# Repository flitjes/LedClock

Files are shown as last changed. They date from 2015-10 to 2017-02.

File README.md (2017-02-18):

A project for creating ledclock. 
The project contains the source for the actual clock and is depended
on a couple of breakouts, RTC, LDR and PIR.

This is tied together with an msp430g2553 to display the time on a ledclock
and be energy sufficient.

Besides the software I've made a 3D drawing which will be milled out of a mix
of materials, plexiglas, carbonfiber and MDF.

Protocol:
Set the time
time=12:10:04
start

setcolor=[id][rgb code]
id 0 = HOUR
id 1 = MINUTE
id 2 = SECOND (not implemented)
id 3 = BACKGROUND (not implemented)

Set the color
setcolor=0ffddff
start

Example with netcat
nc -u 192.168.4.1 12345
setcolor=0ff00ff

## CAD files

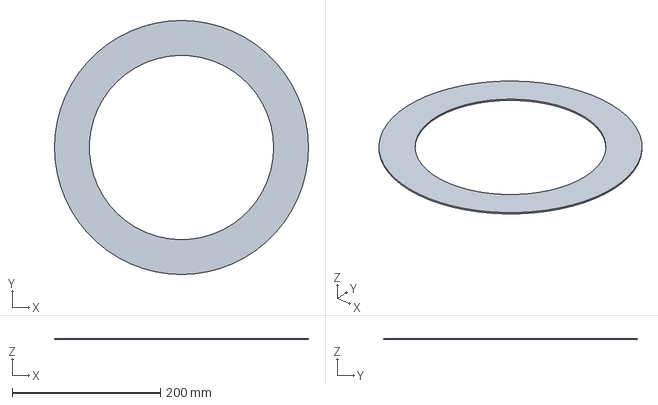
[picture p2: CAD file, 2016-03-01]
FreeCAD/topplate.stp
342.3 x 342.3 x 2.00 mm

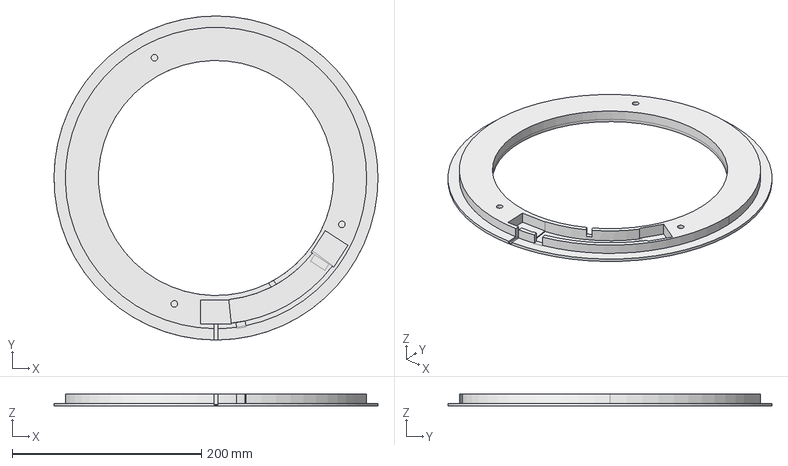
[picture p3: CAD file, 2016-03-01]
FreeCAD/ledclock_base_cutout.fcstd
342.3 x 342.3 x 13.0 mm

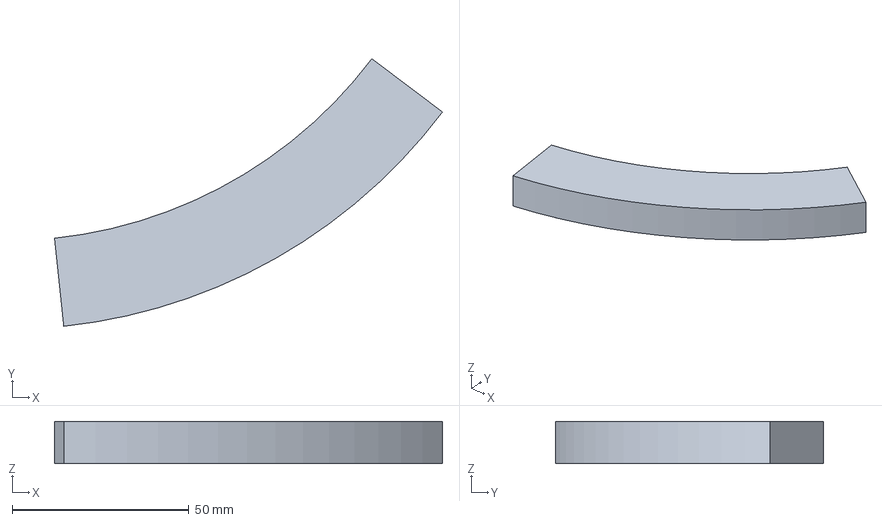
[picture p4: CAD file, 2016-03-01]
FreeCAD/pcb.stp
109.6 x 75.6 x 12.0 mm

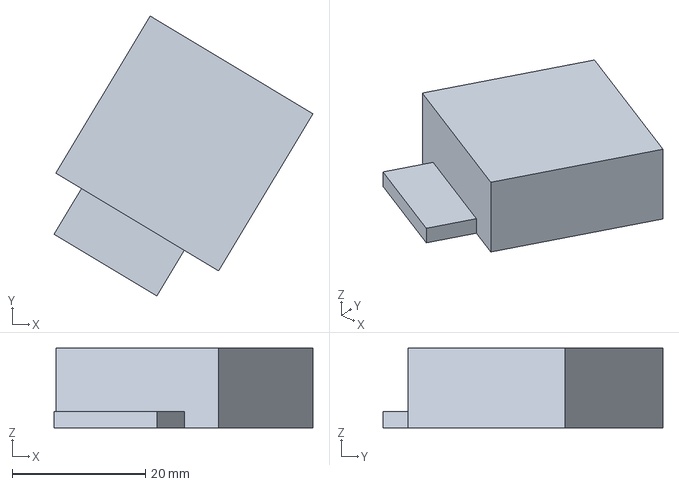
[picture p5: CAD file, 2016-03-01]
FreeCAD/RTC.stp
38.9 x 42.0 x 12.0 mm

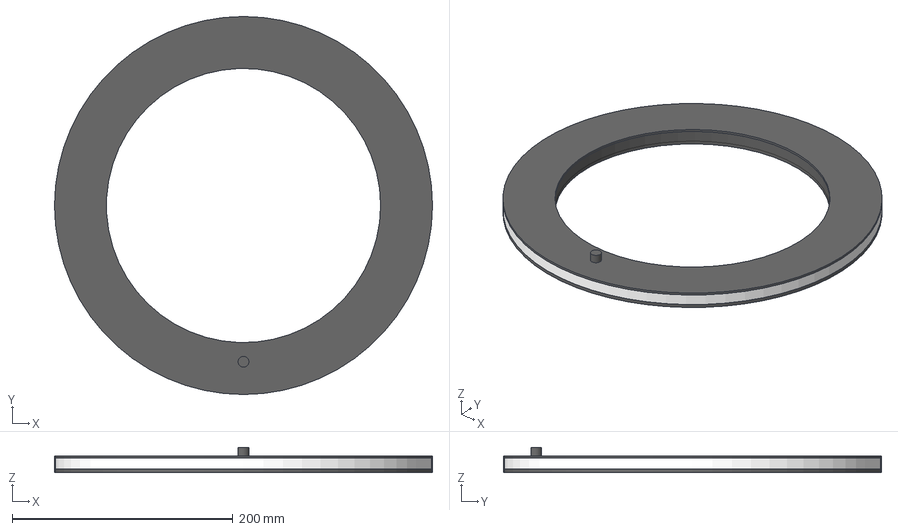
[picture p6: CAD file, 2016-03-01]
FreeCAD/ledclock.fcstd
342.3 x 342.3 x 22.7 mm
topplate_ring
RTC breakout
PIR breakout
Bottom part
PCB
difuser_ring

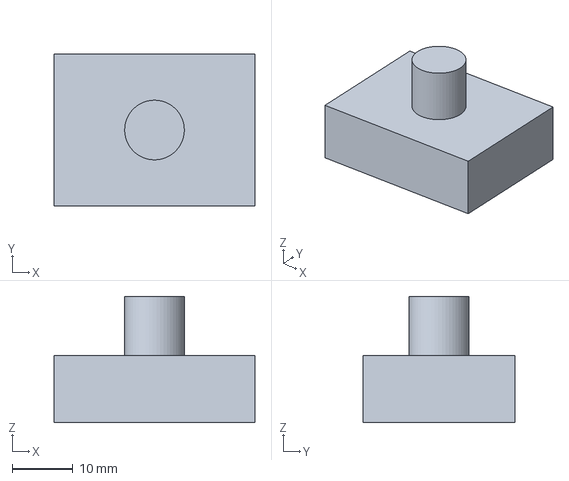
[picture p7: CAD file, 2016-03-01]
FreeCAD/pir_sensor.stp
33.0 x 25.0 x 20.7 mm

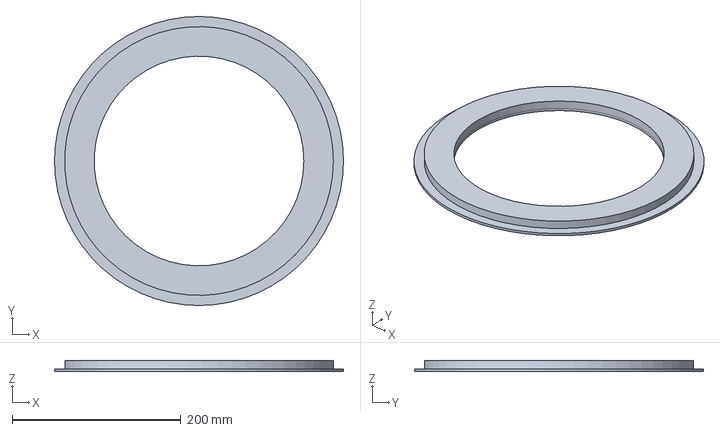
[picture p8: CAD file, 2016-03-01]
FreeCAD/bottom.stp
342.3 x 342.3 x 13.0 mm

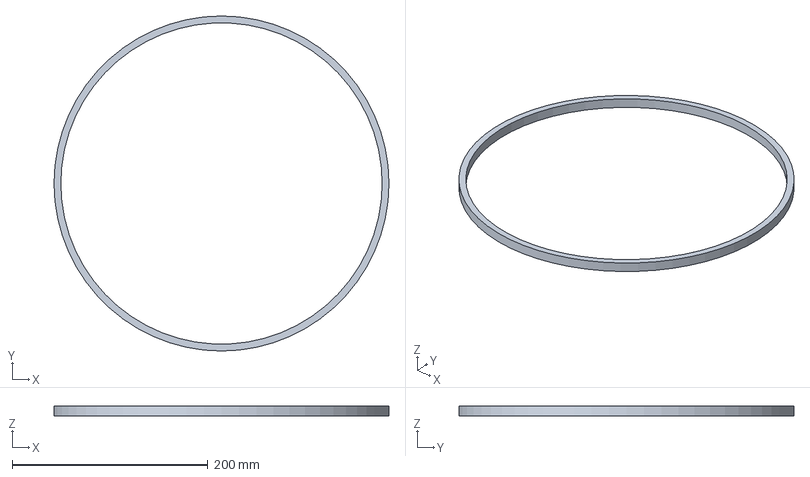
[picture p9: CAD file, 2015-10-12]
FreeCAD/diffuser_ring.stp
342.3 x 342.3 x 10.0 mm

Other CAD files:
FreeCAD/topplate.fcstd

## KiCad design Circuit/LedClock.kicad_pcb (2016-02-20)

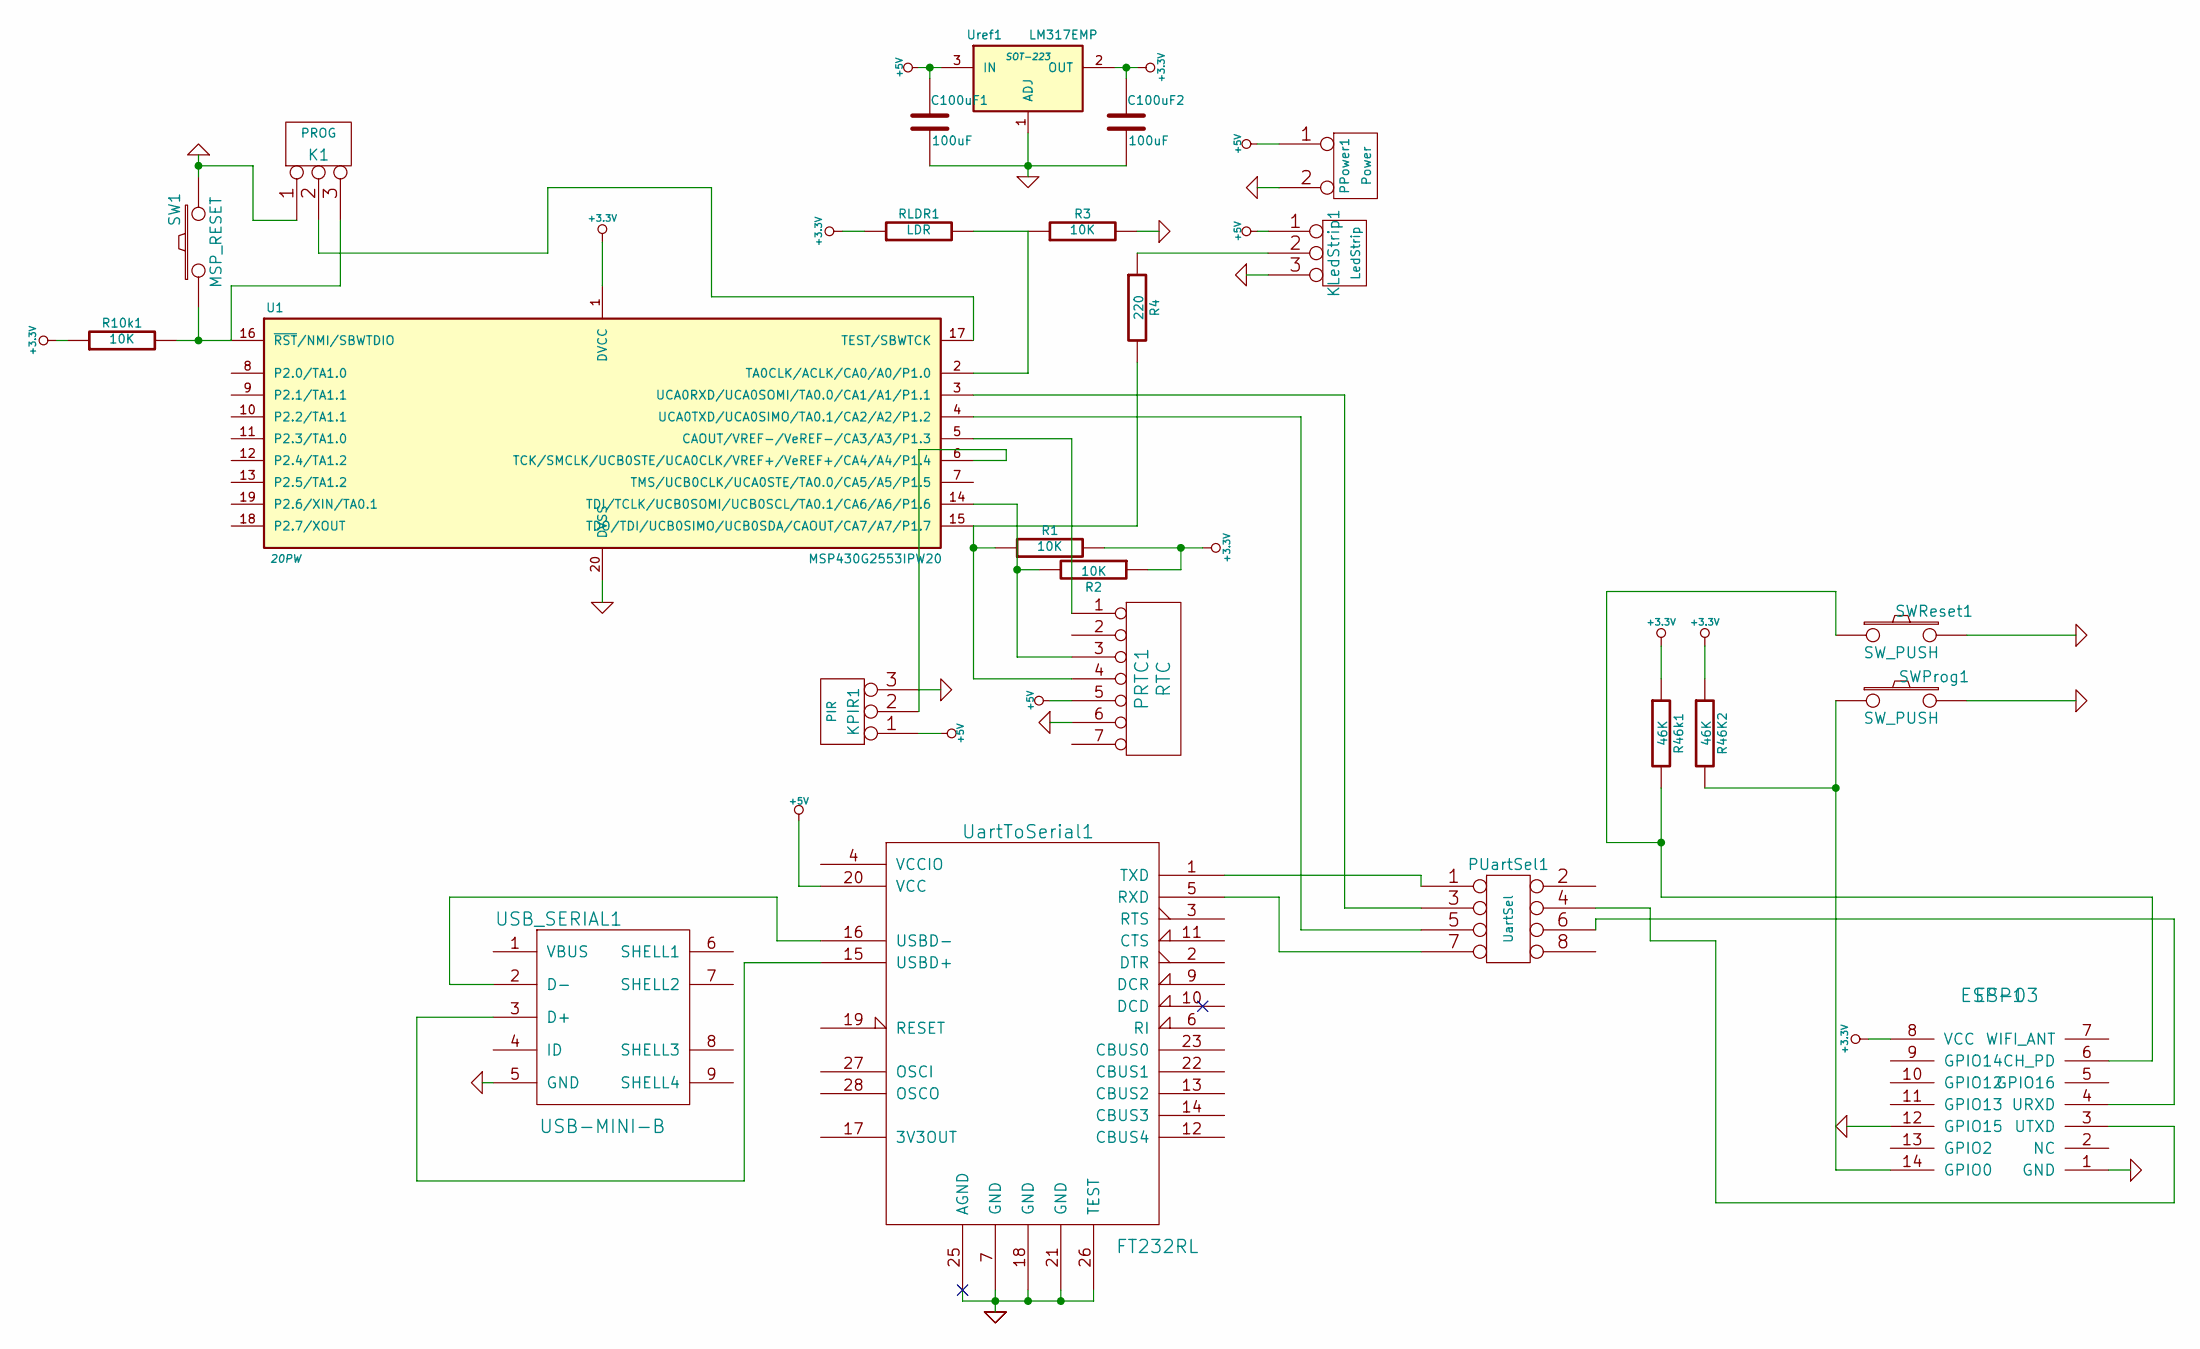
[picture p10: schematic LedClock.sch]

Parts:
C100uF1, C100uF2: 100uF
ESP1: ESP-03
K1: PROG
KLedStrip1: LedStrip
KPIR1: PIR
PPower1: Power
PRTC1: RTC
PUartSel1: UartSel
R1, R2, R3, R10k1: 10K
R4: 220
R46K2, R46k1: 46K
RLDR1: LDR
SW1: MSP_RESET
SWProg1: SW_PUSH
SWReset1: SW_PUSH
U1: MSP430G2553IPW20; 20PW
USB_SERIAL1: USB-MINI-B
UartToSerial1: FT232RL
Uref1: LM317EMP; SOT-223

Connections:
+3.3V: C100uF2.1, ESP1.8 (VCC), R1.2, R2.1, R10k1.1, R46K2.1, R46k1.1, RLDR1.1, U1.1 (DVCC), Uref1.2 (OUT)
+5V: C100uF1.1, KLedStrip1.1, KPIR1.1, PPower1.1, PRTC1.5, UartToSerial1.20 (VCC), Uref1.3 (IN)
GND: C100uF1.2, C100uF2.2, ESP1.1 (GND), ESP1.12 (GPIO15), K1.1, KLedStrip1.3, KPIR1.3, PPower1.2 (PM), PRTC1.6, R3.2, SW1.2, SWProg1.2, SWReset1.2, U1.20 (DVSS), USB_SERIAL1.5 (GND), UartToSerial1.7 (GND), UartToSerial1.18 (GND), UartToSerial1.21 (GND), UartToSerial1.25 (AGND), UartToSerial1.26 (TEST), Uref1.1 (ADJ)
unnamed: USB_SERIAL1.3 (D+), UartToSerial1.15 (USBD+)
unnamed: PUartSel1.7, UartToSerial1.5 (RXD)
unnamed: R3.1, RLDR1.2, U1.2 (TA0CLK/ACLK/CA0/A0/P1.0)
unnamed: KPIR1.2 (PM), U1.6 (TCK/SMCLK/UCB0STE/UCA0CLK/VREF+/VeREF+/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)
unnamed: PUartSel1.1, UartToSerial1.1 (TXD)
unnamed: PUartSel1.3, U1.3 (UCA0RXD/UCA0SOMI/TA0.0/CA1/A1/P1.1)
unnamed: PUartSel1.5, U1.4 (UCA0TXD/UCA0SIMO/TA0.1/CA2/A2/P1.2)
unnamed: USB_SERIAL1.2 (D-), UartToSerial1.16 (USBD-)
unnamed: PRTC1.1, U1.5 (CAOUT/VREF-/VeREF-/CA3/A3/P1.3)
unnamed: KLedStrip1.2 (PM), R4.1
unnamed: K1.3, R10k1.2, SW1.1, U1.16 (~RST~/NMI/SBWTDIO)
unnamed: K1.2 (PM), U1.17 (TEST/SBWTCK)
unnamed: ESP1.14 (GPIO0), R46K2.2, SWProg1.1
unnamed: ESP1.6 (CH_PD), R46k1.2, SWReset1.1
unnamed: ESP1.4 (URXD), PUartSel1.6
unnamed: ESP1.3 (UTXD), PUartSel1.4
unnamed: PRTC1.4, R1.1, R4.2, U1.15 (TDO/TDI/UCB0SIMO/UCB0SDA/CAOUT/CA7/A7/P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)
unnamed: PRTC1.3, R2.2, U1.14 (TDI/TCLK/UCB0SOMI/UCB0SCL/TA0.1/CA6/A6/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)

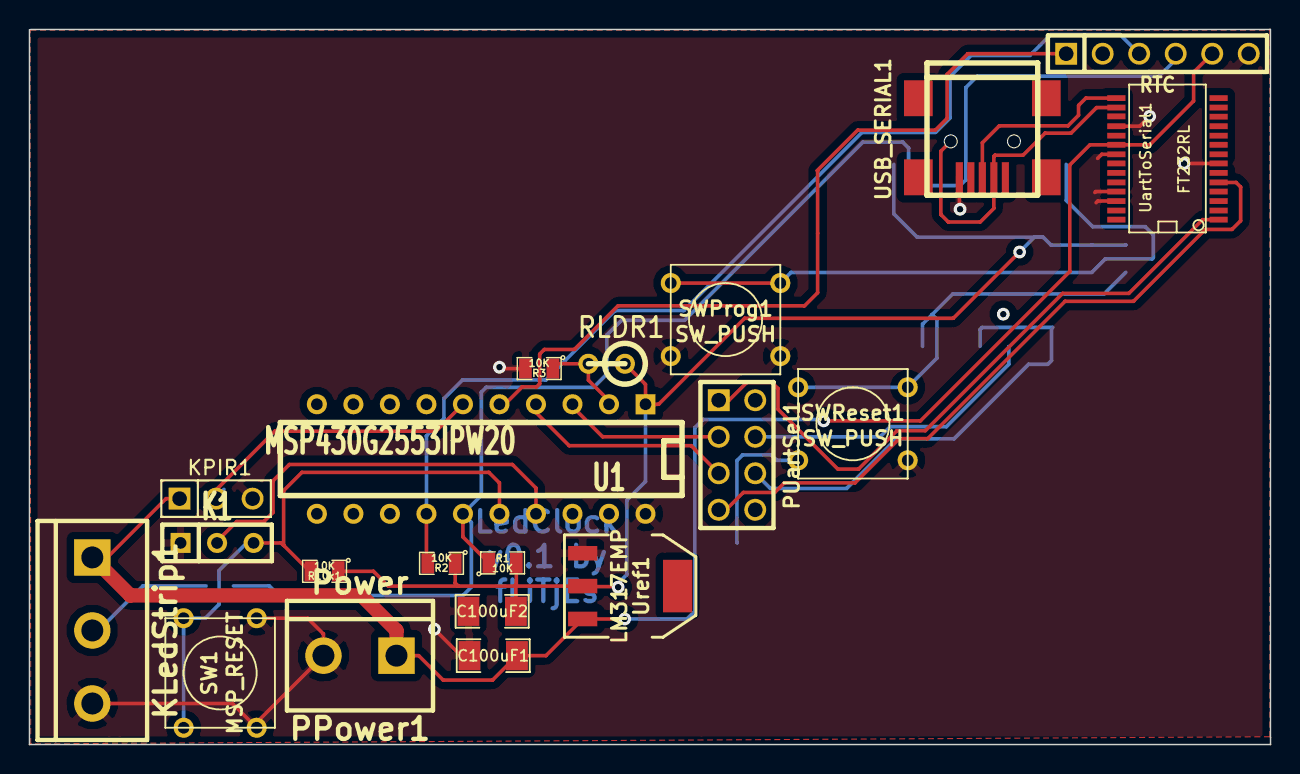
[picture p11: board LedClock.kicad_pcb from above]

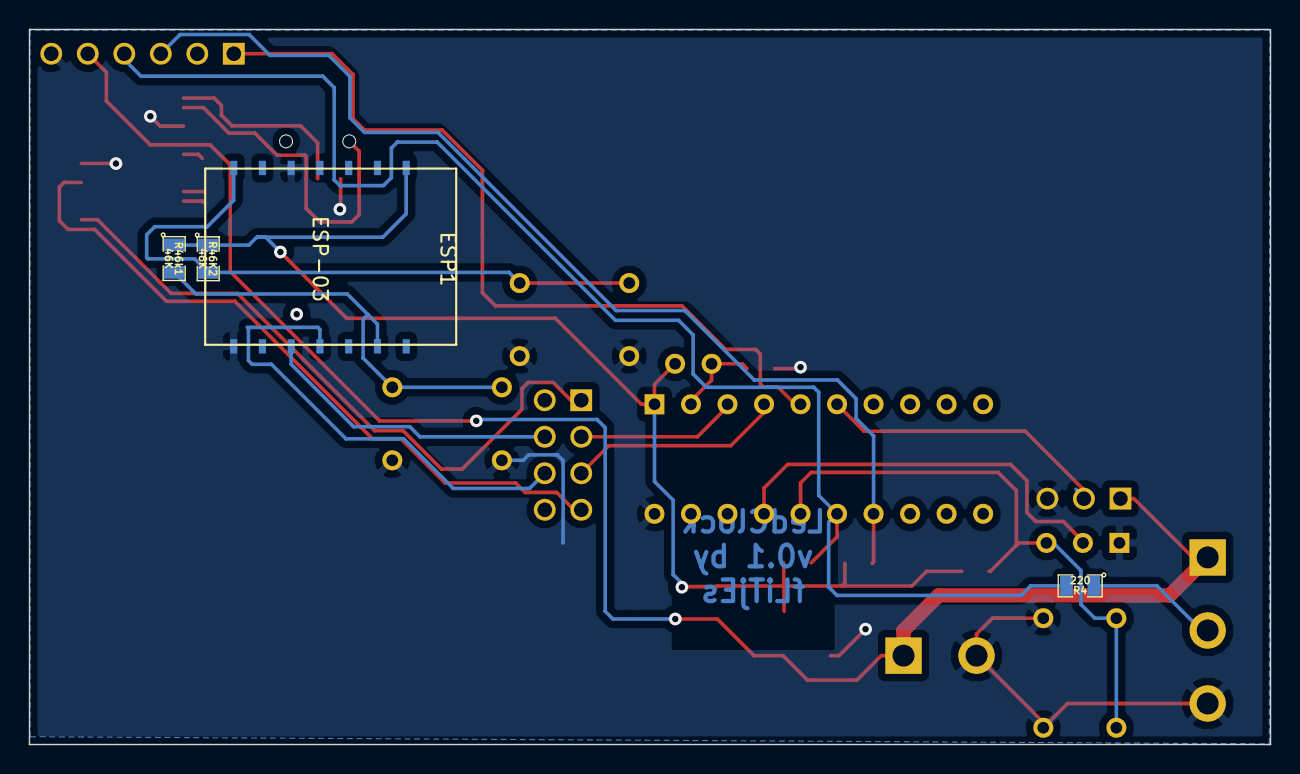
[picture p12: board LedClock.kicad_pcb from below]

Board: 2 copper layers, 86.3 x 49.7 mm, 24 parts (4 on the bottom side), 21 nets.

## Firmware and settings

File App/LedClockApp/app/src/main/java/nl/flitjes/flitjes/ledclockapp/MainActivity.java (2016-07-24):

package nl.flitjes.flitjes.ledclockapp;

import android.graphics.Paint;
import android.os.Bundle;
import android.support.v4.app.DialogFragment;
import android.support.v7.app.AppCompatActivity;
import android.view.View;

public class MainActivity extends AppCompatActivity implements ColorPickerDialog.OnColorChangedListener{
    private Paint mPaint = new Paint();
    private LedClock.COLOR c_id;
    @Override
    protected void onCreate(Bundle savedInstanceState) {
        super.onCreate(savedInstanceState);
        setContentView(R.layout.activity_main);

    }
    public void showTimePickerDialog(View v) {
        DialogFragment newFragment = new TimePickerFragment();
        newFragment.show(getSupportFragmentManager(), "timePicker");
    }

    public void showHourColorPicker(View v) {
        c_id = LedClock.COLOR.HOUR;
        new ColorPickerDialog(this, this, mPaint.getColor()).show();

    }
    public void showMinColorPicker(View v) {
        c_id = LedClock.COLOR.MINUTE;
        new ColorPickerDialog(this, this, mPaint.getColor()).show();
    }

    @Override
    public void colorChanged(int color) {
        LedClock l = new LedClock();
        l.setColor(c_id, color);
    }
}

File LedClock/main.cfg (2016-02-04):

/**
 *  @fileOverview Grace
 */

/* need to use the CSL module to generate the CSL code */
var CSL = xdc.useModule('ti.mcu.msp430.csl.CSL');
var USCI_A0 = xdc.useModule('ti.mcu.msp430.csl.communication.USCI_A0');
var ADC10 = xdc.useModule('ti.mcu.msp430.csl.adc.ADC10');
var USCI_B0 = xdc.useModule('ti.mcu.msp430.csl.communication.USCI_B0');
var Timer0_A3 = xdc.useModule('ti.mcu.msp430.csl.timer.Timer0_A3');
CSL.configApiVersion = "1.20.00";

/* these modules should be part of every project */
var BCSplus = xdc.useModule('ti.mcu.msp430.csl.clock.BCSplus');
var WDTplus = xdc.useModule('ti.mcu.msp430.csl.watchdog.WDTplus');
var System = xdc.useModule('ti.mcu.msp430.csl.system.System');
var GPIO = xdc.useModule('ti.mcu.msp430.csl.gpio.GPIO');
var InterruptVectors = xdc.useModule('ti.mcu.msp430.csl.interrupt_vectors.InterruptVectors');

/* set stack and heap sizes as appropriate for MSP430 */
Program.sysStack = 0;
Program.stack = 64;
Program.heap = 0;
Program.argSize = 0;

/* Enable global interrupt */
System.srRegs.SR.GIE = System.srDefs.GIE;
USCI_A0.toggleButtonUART = true;
USCI_A0.showSelectionPage = false;
USCI_A0.uartRegs.UCA0CTL1.UCSSEL = USCI_A0.uartDefs.UCSSEL_2;
USCI_A0.standardBaudRatesBasicViewUART = USCI_A0.BaudRate_9;
USCI_A0.standardBaudRatesPowerViewUART = USCI_A0.BaudRate_9;
USCI_A0.uartRegs.UCA0BR0 = 138;
USCI_A0.uartRegs.UCA0MCTL.UCBRS = USCI_A0.uartDefs.UCBRS_7;
System.ie2Regs.interruptSource[0].interruptHandler = true;
System.ie2Regs.interruptSource[2].interruptHandler = true;
System.ie2Regs.interruptSource[4].interruptHandler = true;
System.ie2Regs.IE2.UCA0RXIE = System.ie2Defs.UCA0RXIE;
USCI_A0.usciUartPin[0] = 1;
GPIO.regs.P1SEL.Bit1 = GPIO.defs.BIT1;
GPIO.regs.P1SEL2.Bit1 = GPIO.defs.BIT1;
USCI_A0.usciUartPin[1] = 1;
GPIO.regs.P1SEL.Bit2 = GPIO.defs.BIT2;
GPIO.regs.P1SEL2.Bit2 = GPIO.defs.BIT2;
BCSplus.userInputDCO = 16000.0;
BCSplus.regs.LFXT1CLKHz = 12000.0;
BCSplus.regs.BCSCTL3.LFXT1S = BCSplus.defs.LFXT1S_2;
GPIO.regs.P2SEL.Bit6 = GPIO.defs.BIT6_OFF;
GPIO.regs.P2SEL.Bit7 = GPIO.defs.BIT7_OFF;
CSL.device.vcc = 3.6;
GPIO.regs.P1SEL.Bit5 = GPIO.defs.BIT5;
GPIO.regs.P1SEL2.Bit5 = GPIO.defs.BIT5;
GPIO.regs.P1SEL.Bit7 = GPIO.defs.BIT7;
GPIO.regs.P1SEL2.Bit7 = GPIO.defs.BIT7;
ADC10.regs.ADC10AE0 = 1;
ADC10.regs.ADC10CTL0.ADC10ON = ADC10.defs.ADC10ON;
GPIO.regs.P1SEL.Bit6 = GPIO.defs.BIT6;
GPIO.regs.P1SEL2.Bit6 = GPIO.defs.BIT6;
GPIO.regs.P2DIR.Bit5 = GPIO.defs.BIT5_OFF;
GPIO.regs.P2OUT.Bit5 = GPIO.defs.BIT5_OFF;
USCI_B0.toggleButtonI2C = true;
USCI_B0.showSelectionPage = false;
USCI_B0.UCMODE_SYNC = USCI_B0.UCMODE_3;
USCI_B0.i2cRegs.UCB0CTL1.UCSSEL = USCI_B0.i2cDefs.UCSSEL_2;
USCI_B0.i2cRegs.UCB0BR0 = 160;
USCI_B0.i2cRegs.UCB0BR1 = 0;
USCI_B0.usciI2cPin[0] = 1;
USCI_B0.usciI2cPin[1] = 1;
USCI_B0.i2cRegs.UCB0CTL0.UCMST = USCI_B0.i2cDefs.UCMST;
USCI_B0.standardI2CBitRatesBasicView = USCI_B0.I2CBitRate_4;
USCI_B0.standardI2CBitRatesPowerView = USCI_B0.I2CBitRate_4;
USCI_B0.i2cRegs.UCB0I2COA.I2COA = 16;
System.ie2Regs.IE2.UCB0TXIE = System.ie2Defs.UCB0TXIE;
System.ie2Regs.interruptSource[5].interruptHandler = true;
System.ie2Regs.interruptSource[1].interruptHandler = true;
System.ie2Regs.interruptSource[3].interruptHandler = true;
System.ie2Regs.interruptSource[6].interruptHandler = true;
System.ie2Regs.interruptSource[7].interruptHandler = true;
System.ie2Regs.IE2.UCB0RXIE = System.ie2Defs.UCB0RXIE;
GPIO.regs.P2REN.Bit5 = GPIO.defs.BIT5_OFF;
GPIO.regs.P2IE.Bit5 = GPIO.defs.BIT5_OFF;
GPIO.regs.P2IES.Bit5 = GPIO.defs.BIT5_OFF;
GPIO.regs.interruptSource[13].interruptHandler = false;
GPIO.regs.interruptSource[8].interruptHandler = false;
GPIO.regs.interruptSource[9].interruptHandler = false;
GPIO.regs.interruptSource[10].interruptHandler = false;
GPIO.regs.interruptSource[11].interruptHandler = false;
GPIO.regs.interruptSource[12].interruptHandler = false;
GPIO.regs.interruptSource[14].interruptHandler = false;
GPIO.regs.interruptSource[15].interruptHandler = false;
GPIO.regs.P1IE.Bit3 = GPIO.defs.BIT3;
GPIO.regs.P1IES.Bit3 = GPIO.defs.BIT3;
GPIO.regs.interruptSource[3].interruptHandler = true;
GPIO.regs.interruptSource[0].interruptHandler = true;
GPIO.regs.interruptSource[1].interruptHandler = true;
GPIO.regs.interruptSource[2].interruptHandler = true;
GPIO.regs.interruptSource[4].interruptHandler = true;
GPIO.regs.interruptSource[5].interruptHandler = true;
GPIO.regs.interruptSource[6].interruptHandler = true;
GPIO.regs.interruptSource[7].interruptHandler = true;
GPIO.regs.P1IE.Bit4 = GPIO.defs.BIT4_OFF;
Timer0_A3.ccr0TimerSelection_BasicView = xdc.module("ti.mcu.msp430.csl.timer.ITimer").CCR0TimerSelection_BasicView_Selection_1;
Timer0_A3.ccr0TimerSelection_PowerUser = xdc.module("ti.mcu.msp430.csl.timer.ITimer").CCR0TimerSelection_PowerUser_Selection_1;
Timer0_A3.ccInputPin[0] = 0;
Timer0_A3.regs.TA0CTL.MC = Timer0_A3.defs.MC_1;
Timer0_A3.regs.TA0CCR0 = 59999;
Timer0_A3.ccrOutputPin[0] = 0;
Timer0_A3.regs.TA0CTL.TASSEL = Timer0_A3.defs.TASSEL_1;
Timer0_A3.inputClockToTimer = 12.0;
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

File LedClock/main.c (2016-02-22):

/*
 * ======== Standard MSP430 includes ========
 */
#include <msp430.h>

/*
 * ======== Grace related includes ========
 */
#include <ti/mcu/msp430/Grace.h>

#include "serial.h"
#include "time.h"
#include "ws2812.h"
#include "state.h"
#include "animation.h"
#include <stdint.h>
#include "debug.h"
#include "DS1307.h"

uint8_t allignment_offset = 31;
/*
 *  ======== main ========
 */

int main(void)
{
	//During Grace init P1.6 and P1.7 are configured as I2C for the RTC

    Grace_init();                   // Activate Grace-generated configuration
    struct time_t parsed;
    struct time_t rtc = { 0, 0, 0 };
    uint8_t previous_second = 120;
    ds1307_set_squarewave(1);

    switch_state(INIT);

    // >>>>> Fill-in user code here <<<<<
    for(;;){
		switch(current_state){
		    case INIT:
		    	ds1307_get_time(&rtc);
		    	// initialize LED strip
				initStrip(allignment_offset);

				set_time(&rtc);
		    	P1IE |= BIT3;
				// set strip color red
				fillStrip(0xFF, 0x00, 0x00);

				print_string("LedClock started\n");
				switch_state(RUNNING);
		    	break;
		    case SET_TIME:
		    	P1IE &= ~(BIT3);

				parse_time(time_formated+1, &parsed);
				set_time(&parsed);

				ds1307_set_time(&parsed);

				// initialize LED strip
				initStrip(allignment_offset);

				f_time_set = 0;
				switch_state(RUNNING);
		    	break;
		    case RUNNING:
		    	//__delay_cycles(100000); //6.25 milisecond
		    	if (current.second != previous_second){
		    		previous_second = current.second;
					#ifdef DEBUG
						sprintf(debug_str, "Time: %d:%d:%d\n", current.hour, current.minute, current.second);
						print_string(debug_str);
					#endif

					if(P1IN & BIT4){
						show_clock(&current);

					} else {
						fillStrip(0x00, 0x00, 0x00);
					}
		    	}
		    	break;
		    case STOP:
		    	P1IE &= ~(BIT3);
		    	break;
		    case PRINT_TIME:
				print_time();
				switch_state(previous_state);
				break;
		    case SHOW_DATA:
		    	P1IE &= ~(BIT3);
		    	showStrip();
		    	switch_state(STOP);
		    	break;
		    default:
		    	print_string("Non defined case, possible stack corruption\n");
		    	break;
		}
    }

}

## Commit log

2015-07-12 Updated with statemachine
    [build.cfg, main.cfg, main_pe430.cfg]
2015-07-12 Fixed animation birghtness of trailing leds
    [animation.c]
2015-07-12 Added brightness control Removed the amount of leds from the animation call
2015-07-25 Enabled dynamic brightness controll based on an LDR connected to the ADC channel 0 on P1.0
    [main.cfg, main_pe430.cfg]
2015-07-25 Fixed 3 pin mode initalisation for SPI
    [ws2812.c]
2015-07-25 Fixed SPI init in ws2812.c Adding ADC and USCI_B0 and debug.h forgot those in previous commits..
    [main.cfg]
2015-07-25 Removed all unneccesary config and debug files from the repo
    [build.cfg, main_pe430.cfg]
2015-07-26 Added multiplex pin P2.5 to controll the mux for switching SDA between I2C devices and ws2812
    P2.5
    high == ws2812 low == I2C bus
    [main.cfg]
2015-08-04 Added I2C and RTC support Reading and writing to I2C work HW support for toggling is not in place yet Printing of current time is incorrect
    [main.cfg]
2015-08-04 Updated driver with only setting and clearing bits instead of wiping out the entire register..
2015-08-12 Added cad drawing, in progress
    [ledclock.fcstd]
2015-08-23 Added led offset for led 0, incase the ledstrip is mounted not as expected
2015-08-23 Added state history and switching function. Introduced new state logging. Added print time feature
2015-08-23 Removed pin toggle for switching spi and i2c, not necessary any more. Disabled debug
2015-08-23 Led clock will start after init
2015-08-23 I2C read write wrappers added
    [main.cfg]
2015-08-23 Changed from internal timer to external I/O from RTC
    [main.cfg]
2015-08-23 Cleaned up old timer code
    [main.cfg]
2015-08-23 Human presence detection with PIR.
    [main.cfg]
2015-08-24 Found bug, time was standing still when the leds where off...
    [main.c]
2015-08-24 Updated ledclock design. Made primitive objects for the cuttouts.
    [ledclock.fcstd]
2015-09-03 Added gamma correction and base brighness value
    [animation.c, main.c]
2015-09-04 Added schematic and boardlayout
    [LedClock.kicad_pcb, LedClock.sch]
2015-09-05 Added current limiting resistor on the ledstrip data line Adviced by adafruit
    [LedClock.kicad_pcb, LedClock.sch]
2015-09-05 Updated cad drawing based on actual pcb sizes
    [ledclock.fcstd]
2015-09-08 Updated clock prototype after lasercutting
    [ledclock.fcstd]
2015-09-13 Start stop feature broke after swap to gpio interrupt. Fixed it now.
    [main.c]
2015-09-14 Added data transfer option Disabled moving average, calculation should be moved to a timer Initialised ws2812 Added show data state
2015-09-15 Fixed clock not turning on after PIR timeout
    [main.c]
2015-09-26 Updated layout to fit the new ring and stay within 10*5cm
    [LedClock.kicad_pcb, LedClock.sch]
2015-09-27 Updated pcb w.r.t design rules and unconnected parts
    [LedClock.kicad_pcb]
2015-09-27 Updated width of power line accoording to spec
    [LedClock.kicad_pcb]
2015-09-29 Changed clock width
    [ledclock.fcstd]
2015-10-12 Updated ledclock and sperrated everything in parts
    [RTC.stp, bottom.stp, diffuser_ring.stp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]
2015-10-12 Revert "Removed commented default values"
    This reverts commit 6a37c44d4b0144f7c01ff915d57850a3c0bc1299.
    [animation.c]
2015-10-12 Added Gerbers
    [LedClock-B_Cu.gbl, LedClock-B_SilkS.gbo, LedClock-F_Cu.gtl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]
2015-10-12 Updated schematic
    [LedClock.sch]
2015-10-12 Separte modules are exported as parts
    [ledclock.fcstd]
2015-10-12 Base with cutouts
    [ledclock_base_cutout.fcstd]
2015-10-12 Updated parts and design with correct placements
    [RTC.stp, bottom.stp, ledclock.fcstd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]
2015-12-30 Fixed timer issue, could count past 60 if timer interrupt interrupted ticking. Moved moving average to seperate interrupt handler, no need to calculate the brightness every second
    [main.cfg]
2016-01-08 Updted design
    [ledclock_base_cutout.fcstd]
2016-01-11 Updated pcb with cutting edges, fixed minor issue and put name and version on pcb
    [LedClock-B_Cu.gbl, LedClock-B_Mask.gbs, LedClock-B_SilkS.gbo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]
2016-01-21 changed setting led strip with certain length to handle a circle
2016-01-31 Fixed 24 hour input, will be transformed to 12 hour format
    [animation.c]
2016-01-31 Moved clock handling outside of interrupt handler Updating every modulo 10 of a second
2016-02-04 Moved interrupt handlers from main into vector.c because naming changed.. Fixed 24 hour format because 12 was not the correct value
2016-02-04 Updated animation with clear spots indicating the arrows and changed the interrupt handlig inside the vector
    [main.cfg]
2016-02-20 Updated pcb layout and circuit, found 1 flaw in the design
    [LedClock.kicad_pcb, LedClock.sch]
2016-02-22 Fixed setting color and moved the LED offset by 1 for current install. After fresh IDE install some stuff is updated
2016-03-01 Updated 3d model to be thinner and added magnet pockets and ldr pocket
    [RTC.stp, bottom.stp, ledclock.fcstd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]
